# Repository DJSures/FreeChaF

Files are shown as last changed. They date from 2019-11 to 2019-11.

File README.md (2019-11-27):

# FreeChaF
This fork is of FreeChaF with changes to use the Fairchild Channel F original controllers and console buttons connected to a raspberry pi via Arduino Micro or Leonardo. Original Repo here: https://github.com/libretro/FreeChaF

In this repo, you will find David's modified FreeChaF for real hardware, and the arduino code that emulates USB joystick and USB keyboard devices. The wiring of each controller direction to corresponding arduino i/o pin is located in the INO file.

View DJ's build live hack here: https://synthiam.com/Community/HackEvents/Hacking-decision-C64-or-Fairchild-Channel-F-18819

# Folders
/3D Printing - contains the design files for 3d printing the console button holder

/Fairchild_Pi_Joystick_Paddle_Multi - Arduino Micro firmware for the USB joystick emulator

/Fairchild_Pi_Keyboard_Switches - Arduino Micro firmware for the USB keyboard emulator that emulates the console buttons

/FreeChaF-master - The lib retro freechaf emulator src modified for real hardware

# Dj's Hacked Fairchild Example

Channel F with raspberry pi and two arduinos emulating the joysticks and console buttons
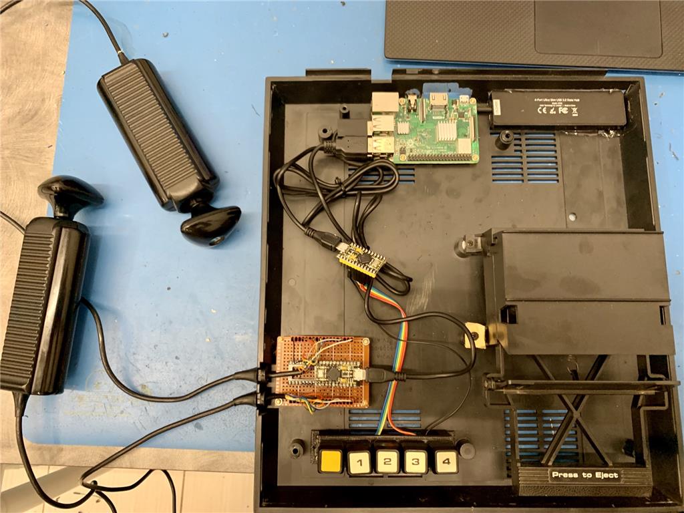
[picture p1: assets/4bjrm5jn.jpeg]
Image of hacked fairchild channel f


The raspberry pi mounted with stand-offs exposing the hdmi and power via a hole cut in the back of the channel f chassis
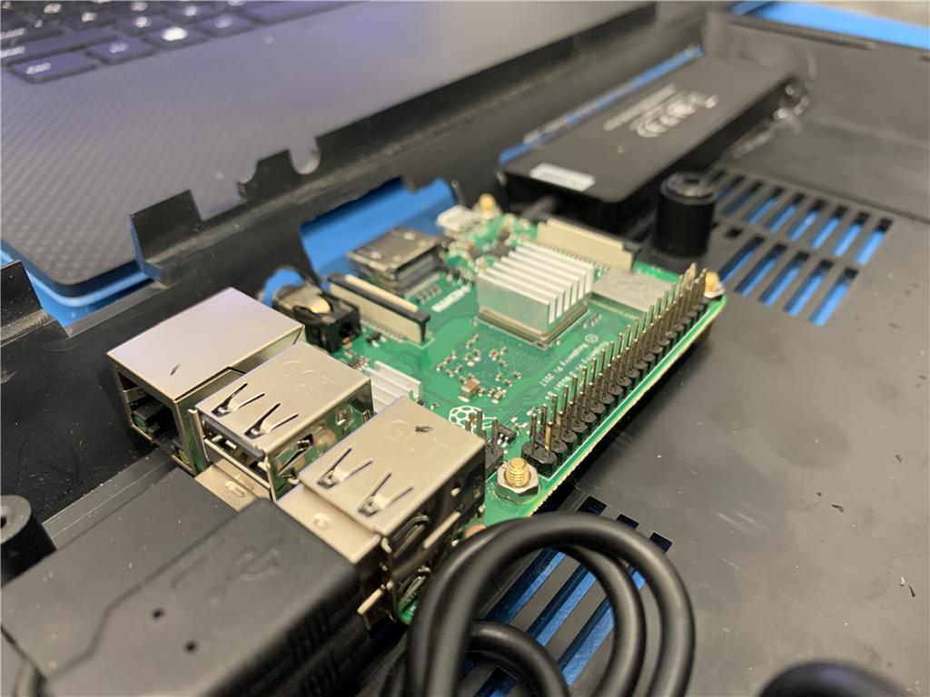
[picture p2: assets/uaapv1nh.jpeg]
Image of raspberry pi in fairchild channel f


The arduino micro that emulates a USB Keyboard device and connects to the console buttons
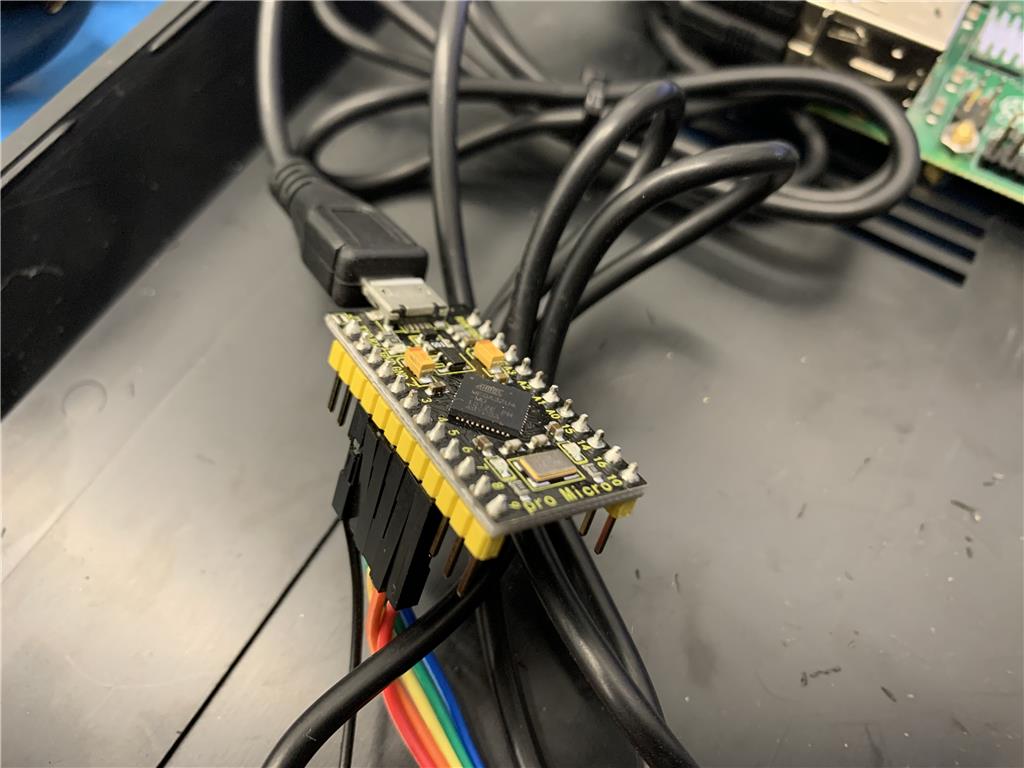
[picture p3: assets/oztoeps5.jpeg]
Image of Arduino for fairchild channel f console emulator


The console buttons held with a 3d printed bracket 
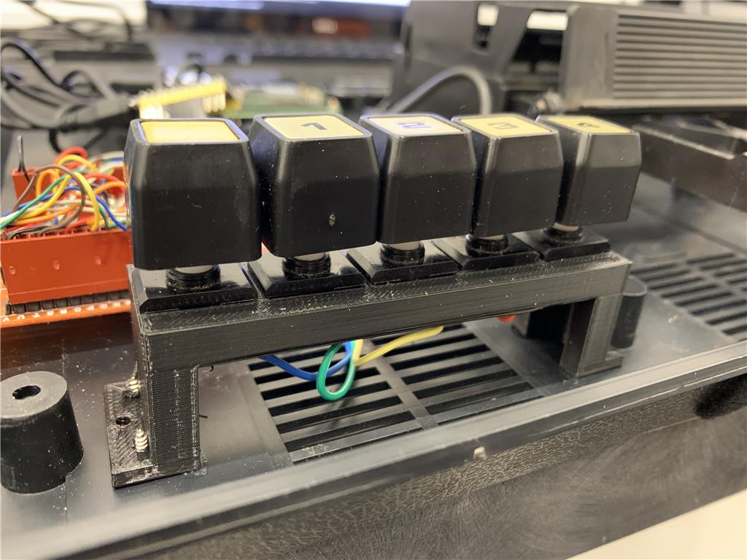
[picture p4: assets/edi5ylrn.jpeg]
Image of fairchild channel f console buttons 3d printed holder


The arduino micro that emulates 2 USB joysticks for the channel f joysticks
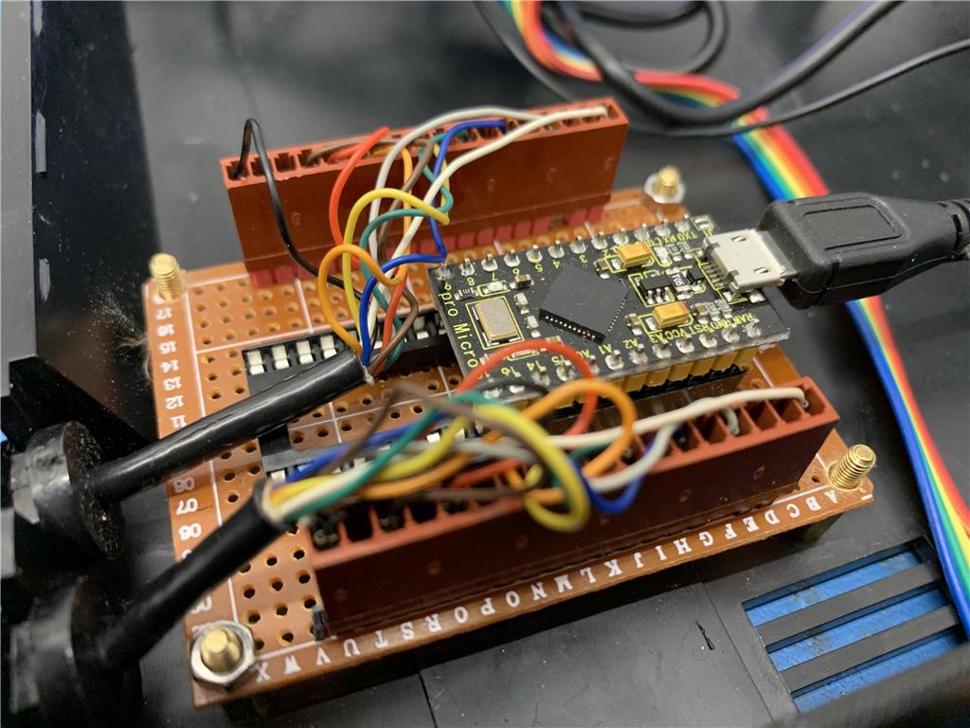
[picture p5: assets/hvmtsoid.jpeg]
Image of arduino joystick emulator for fairchild channel f


## Authors
FreeChaF was created by David Richardson.
This fork for real hardware by DJ Sures

## License
The FreeChaF core is licensed under GPLv3.

## BIOS
FreeChaF requires two BIOS files to be placed in the libretro 'system' folder:

| Filename | Description | MD5 |
|---|---|---|
| sl31253.bin | ChannelF BIOS (PSU 1) | ac9804d4c0e9d07e33472e3726ed15c3 |
| sl31254.bin | ChannelF BIOS (PSU 2) | da98f4bb3242ab80d76629021bb27585 |

If the ChannelF II BIOS is included, it will be used instead of sl31253.  All games are compatible with both.

| Filename | Description | MD5 |
|---|---|---|
| sl90025.bin | ChannelF II BIOS (PSU 1) | 95d339631d867c8f1d15a5f2ec26069d |

* BIOS filenames are case-sensitive

## Console buttons
Access to the console buttons are provided by the Arduino. The LibRetro configuration should have the assignments of numeric values 1, 2, 3, 4 to buttons A, B, X, Z. When a button is pressed, a console overlay will display that shows what button was pressed.

## Controls
| FreeChaF Function | Retropad | Keyboard Assignment |
| --- | --- | --- |
|Forward| Left-Analog Up||
|Backward| Left-Analog Down||
|Rotate Left | Right-Analog Left ||
|Rotate Right | Right-Analog Right ||
|Pull Up | Right-Analog Up ||
|Push Down | Right-Analog Down ||
|Show/Hide Console Overlay | Start | q |
|Controller Swap | Select | w |
|Reset | Left Trigger | R | 
|Console 1 | A | 1 |
|Console 2 | B | 2 |
|Console 3 | X | 3 | 
|Console 4 | Z | 4 |

## How to
Installing this in a fairchild channel f is quite easy. 

1) Open the fairchild channel f and remove the PCB

2) Disconnect the power adapter and joysticks

3) Desolder the console buttons (careful, this is an old machine)

4) 3D print the console button holder

5) Solder the console buttons with a common GND. Each other wire connects to the Arduino pins documented in the Arduino folder's Keyboard firmware code

6) Solder the joystick switches to the USB Joystick arduino micro. The pins are documented in the code. The WHITE wire gets GND

7) Program both of the Arduino's with their respective code

8) Build the freechaf for lib retro by copying the FreeChaf-Master folder to your raspberry pi

9) type make in the freechaf-master folder

10) chmod +x ./install.sh ; ./install.sh

11) load emulation station and configure the buttons appropiately 

12) Have fun!

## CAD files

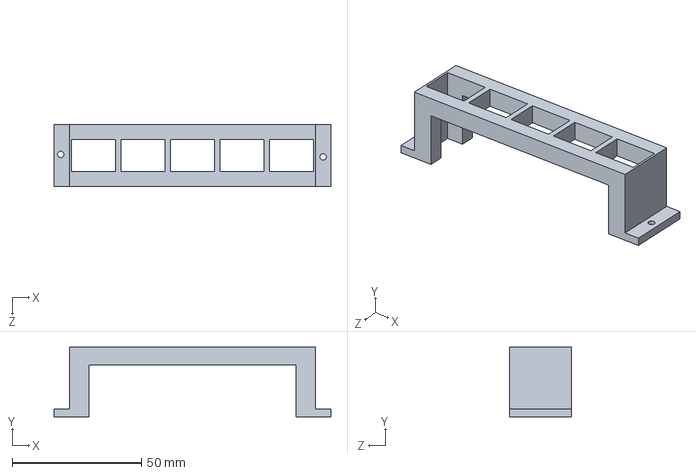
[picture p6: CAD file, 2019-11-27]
3D Printing/Button Holder.SLDPRT
107.0 x 27.0 x 24.0 mm

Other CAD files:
3D Printing/Button Holder.STL

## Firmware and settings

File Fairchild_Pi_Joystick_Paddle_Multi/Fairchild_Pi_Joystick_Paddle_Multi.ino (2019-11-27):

#include "Joystick.h"

// ***********************************************************************
// **                                                                   **
// ** Joystick USB HID for Teensy or Pro Micro                          **
// ** By DJ Sures (Synthiam.com) (c)2019                                **
// **                                                                   **
// ** Updated: November 16, 2019                                        **
// **                                                                   **
// ** NOTE                                                              **
// ** ~~~~                                                              **
// ** For this to work on Raspberry Pi (Linux), you need to add the     **
// ** the following to the /boot/cmdline.txt...                         **
// **                                                                   **
// ** usbhid.quirks=0x2341:0x8036:0x040    <- for Leonardo              **
// ** usbhid.quirks=0x2341:0x8037:0x040    <- for Micro                 **
// **                                                                   **
// ***********************************************************************

// uncomment to use for serial terminal debugging rather than usb hid device
// this is so you can see the ascii values to verify
//#define SERIAL_DEBUG

/**
  white - common
  grey - right
  blue - left
  green - reverse
  yellow - forward
  orange - twist left
  red - twist right
  brown - pull up
  black - push down
*/

#define J1RIGHT A3
#define J1LEFT A2
#define J1DOWN A1
#define J1UP A0

// button 0
#define J1TWIST_LEFT 15

// button 1
#define J1TWIST_RIGHT 14

// button 2
#define J1PUSH_DOWN 10

// button 3
#define J1PULL_UP 16

#define J2RIGHT 2
#define J2LEFT 3
#define J2DOWN 4
#define J2UP 5
#define J2TWIST_LEFT 6
#define J2TWIST_RIGHT 7
#define J2PUSH_DOWN 9
#define J2PULL_UP 8


Joystick_ _j1 = Joystick_(
                  0x03,
                  JOYSTICK_TYPE_JOYSTICK,
                  4,
                  0,
                  true,
                  true,
                  false,
                  false,
                  false,
                  false,
                  false,
                  false,
                  false,
                  false,
                  false
                );

Joystick_ _j2 = Joystick_(
                  0x06,
                  JOYSTICK_TYPE_JOYSTICK,
                  4,
                  0,
                  true,
                  true,
                  false,
                  false,
                  false,
                  false,
                  false,
                  false,
                  false,
                  false,
                  false
                );

byte _lastJ1X = 1; // 0 left, 1 center, 2 right
byte _lastJ1Y = 1; // 0 up, 1 center, 2 down
byte _lastJ1TWIST = 1; // 0 twist left, 1 center, 2 twist right
byte _lastJ1PUSH = 1; // 0 push down, 1 center, 2 pull up

byte _lastJ2X = 1; // 0 left, 1 center, 2 right
byte _lastJ2Y = 1; // 0 up, 1 center, 2 down
byte _lastJ2TWIST = 1; // 0 twist left, 1 center, 2 twist right
byte _lastJ2PUSH = 1; // 0 push down, 1 center, 2 pull up

void setup() {

#ifdef SERIAL_DEBUG
  Serial.begin(9600);
#else
  _j1.setXAxisRange(-127, 127);
  _j1.setYAxisRange(-127, 127);
  _j1.begin();

  _j2.setXAxisRange(-127, 127);
  _j2.setYAxisRange(-127, 127);
  _j2.begin();
#endif

  pinMode(J1UP, INPUT_PULLUP);
  pinMode(J1RIGHT, INPUT_PULLUP);
  pinMode(J1DOWN, INPUT_PULLUP);
  pinMode(J1LEFT, INPUT_PULLUP);
  pinMode(J1TWIST_LEFT, INPUT_PULLUP);
  pinMode(J1TWIST_RIGHT, INPUT_PULLUP);
  pinMode(J1PULL_UP, INPUT_PULLUP);
  pinMode(J1PUSH_DOWN, INPUT_PULLUP);

  pinMode(J2UP, INPUT_PULLUP);
  pinMode(J2RIGHT, INPUT_PULLUP);
  pinMode(J2DOWN, INPUT_PULLUP);
  pinMode(J2LEFT, INPUT_PULLUP);
  pinMode(J2TWIST_LEFT, INPUT_PULLUP);
  pinMode(J2TWIST_RIGHT, INPUT_PULLUP);
  pinMode(J2PULL_UP, INPUT_PULLUP);
  pinMode(J2PUSH_DOWN, INPUT_PULLUP);
}

void loop() {

#ifdef SERIAL_DEBUG

  Serial.print(digitalRead(J1UP));
  Serial.print(digitalRead(J1RIGHT));
  Serial.print(digitalRead(J1DOWN));
  Serial.print(digitalRead(J1LEFT));
  Serial.print(digitalRead(J1TWIST_LEFT));
  Serial.print(digitalRead(J1TWIST_RIGHT));
  Serial.print(digitalRead(J1PULL_UP));
  Serial.print(digitalRead(J1PUSH_DOWN));

  Serial.print(" ");

  Serial.print(digitalRead(J2UP));
  Serial.print(digitalRead(J2RIGHT));
  Serial.print(digitalRead(J2DOWN));
  Serial.print(digitalRead(J2LEFT));
  Serial.print(digitalRead(J2TWIST_LEFT));
  Serial.print(digitalRead(J2TWIST_RIGHT));
  Serial.print(digitalRead(J2PULL_UP));
  Serial.print(digitalRead(J2PUSH_DOWN));

  Serial.write("\r\n");

#else

  // ---------------------------------------------------------
  // JOYSTICK 1
  // ---------------------------------------------------------
  {
    byte j1y;

    if (!digitalRead(J1UP))
      j1y = 0;
    else if (!digitalRead(J1DOWN))
      j1y = 2;
    else
      j1y = 1;

    if (j1y != _lastJ1Y) {

      if (j1y == 0)
        _j1.setYAxis(-127);
      else if (j1y == 2)
        _j1.setYAxis(127);
      else
        _j1.setYAxis(0);

      _lastJ1Y = j1y;
    }
  }

  {
    // ---------------------------------------------------------
    byte j1x;

    if (!digitalRead(J1LEFT))
      j1x = 0;
    else if (!digitalRead(J1RIGHT))
      j1x = 2;
    else
      j1x = 1;

    if (j1x != _lastJ1X) {

      if (j1x == 0)
        _j1.setXAxis(-127);
      else if (j1x == 2)
        _j1.setXAxis(127);
      else
        _j1.setXAxis(0);

      _lastJ1X = j1x;
    }
  }

  {
    // ---------------------------------------------------------
    byte j1twist;

    if (!digitalRead(J1TWIST_LEFT))
      j1twist = 0;
    else if (!digitalRead(J1TWIST_RIGHT))
      j1twist = 2;
    else
      j1twist = 1;

    if (j1twist != _lastJ1TWIST) {

      if (j1twist == 0) {

        _j1.setButton(0, true);
        _j1.setButton(1, false);
      }  else if (j1twist == 2) {

        _j1.setButton(0, false);
        _j1.setButton(1, true);
      } else {

        _j1.setButton(0, false);
        _j1.setButton(1, false);
      }

      _lastJ1TWIST = j1twist;
    }
  }

  {
    // ---------------------------------------------------------
    byte j1push;

    if (!digitalRead(J1PUSH_DOWN))
      j1push = 0;
    else if (!digitalRead(J1PULL_UP))
      j1push = 2;
    else
      j1push = 1;

    if (j1push != _lastJ1PUSH) {

      if (j1push == 0) {

        _j1.setButton(2, true);
        _j1.setButton(3, false);
      }  else if (j1push == 2) {

        _j1.setButton(2, false);
        _j1.setButton(3, true);
      } else {

        _j1.setButton(2, false);
        _j1.setButton(3, false);
      }

      _lastJ1PUSH = j1push;
    }
  }

  // ---------------------------------------------------------
  // JOYSTICK 2
  // ---------------------------------------------------------
  {
    byte j2y;

    if (!digitalRead(J2UP))
      j2y = 0;
    else if (!digitalRead(J2DOWN))
      j2y = 2;
    else
      j2y = 1;

    if (j2y != _lastJ2Y) {

      if (j2y == 0)
        _j2.setYAxis(-127);
      else if (j2y == 2)
        _j2.setYAxis(127);
      else
        _j2.setYAxis(0);

      _lastJ2Y = j2y;
    }
  }

  {
    byte j2x;

    if (!digitalRead(J2LEFT))
      j2x = 0;
    else if (!digitalRead(J2RIGHT))
      j2x = 2;
    else
      j2x = 1;

    if (j2x != _lastJ2X) {

      if (j2x == 0)
        _j2.setXAxis(-127);
      else if (j2x == 2)
        _j2.setXAxis(127);
      else
        _j2.setXAxis(0);

      _lastJ2X = j2x;
    }
  }
  
  // ---------------------------------------------------------
  {
    byte j2twist;

    if (!digitalRead(J2TWIST_LEFT))
      j2twist = 0;
    else if (!digitalRead(J2TWIST_RIGHT))
      j2twist = 2;
    else
      j2twist = 1;

    if (j2twist != _lastJ2TWIST) {

      if (j2twist == 0) {

        _j2.setButton(0, true);
        _j2.setButton(1, false);
      }  else if (j2twist == 2) {

        _j2.setButton(0, false);
        _j2.setButton(1, true);
      } else {

        _j2.setButton(0, false);
        _j2.setButton(1, false);
      }

      _lastJ2TWIST = j2twist;
    }
  }

  {
    // ---------------------------------------------------------
    byte j2push;

    if (!digitalRead(J2PUSH_DOWN))
      j2push = 0;
    else if (!digitalRead(J2PULL_UP))
      j2push = 2;
    else
      j2push = 1;

    if (j2push != _lastJ2PUSH) {

      if (j2push == 0) {

        _j2.setButton(2, true);
        _j2.setButton(3, false);
      }  else if (j2push == 2) {

        _j2.setButton(2, false);
        _j2.setButton(3, true);
      } else {

        _j2.setButton(2, false);
        _j2.setButton(3, false);
      }

      _lastJ2PUSH = j2push;
    }
  }
  
#endif

  delay(25);
}

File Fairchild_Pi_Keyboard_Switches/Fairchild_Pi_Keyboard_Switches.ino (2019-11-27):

#include "Keyboard.h"

// ***********************************************************************
// **                                                                   **
// ** Keyboard USB HID for Teensy or Pro Micro                          **
// ** By DJ Sures (Synthiam.com) (c)2019                                **
// **                                                                   **
// ** Updated: November 15, 2019                                        **
// **                                                                   **
// ***********************************************************************

// uncomment to use for serial terminal debugging rather than usb hid device
// this is so you can see the ascii values to verify
//#define SERIAL_DEBUG

#define SWITCH_RESET 2
#define SWITCH_S1 3
#define SWITCH_S2 4
#define SWITCH_S3 5
#define SWITCH_S4 6

bool _last_reset = false;
bool _last_s1 = false;
bool _last_s2 = false;
bool _last_s3 = false;
bool _last_s4 = false;
bool _last_start = false;
bool _last_select = false;

void setup() {

#ifdef SERIAL_DEBUG
  Serial.begin(9600);
#else
  Keyboard.begin();
#endif

  pinMode(SWITCH_RESET, INPUT_PULLUP);
  pinMode(SWITCH_S1, INPUT_PULLUP);
  pinMode(SWITCH_S2, INPUT_PULLUP);
  pinMode(SWITCH_S3, INPUT_PULLUP);
  pinMode(SWITCH_S4, INPUT_PULLUP);
}

void loop() {

#ifdef SERIAL_DEBUG

  Serial.print(!digitalRead(SWITCH_RESET));
  Serial.print(!digitalRead(SWITCH_S1));
  Serial.print(!digitalRead(SWITCH_S2));
  Serial.print(!digitalRead(SWITCH_S3));
  Serial.print(!digitalRead(SWITCH_S4));
  Serial.print("\r\n");

#else

  bool reset = !digitalRead(SWITCH_RESET);
  bool s1 = !digitalRead(SWITCH_S1);
  bool s2 = !digitalRead(SWITCH_S2);
  bool s3 = !digitalRead(SWITCH_S3);
  bool s4 = !digitalRead(SWITCH_S4);
  bool select = !digitalRead(SWITCH_RESET) && !digitalRead(SWITCH_S1);
  bool start = !digitalRead(SWITCH_RESET) && !digitalRead(SWITCH_S2);

 if (select != _last_select) {

    if (select) 
      Keyboard.press('q');
    else
      Keyboard.release('q');

    _last_select = select;
  }

  if (start != _last_start) {

    if (start) 
      Keyboard.press('w');
    else
      Keyboard.release('w');

    _last_start = start;
  }

  // no need to process anything further because 
  if (reset || select || start)
    return;

  if (reset != _last_reset) {

    if (reset) {

        // TODO: emulator needs support for RESET button
        // exit emulator now by pressing SELECT & START (reset + time + mode)
//      Keyboard.press('q');
//      Keyboard.press('w');
//      delay(250);
//      Keyboard.releaseAll();
    }

    _last_reset = reset;
  }
  
  if (s1 != _last_s1) {

    if (s1)
      Keyboard.press('1');
    else
      Keyboard.release('1');

    _last_s1 = s1;
  }

  if (s2 != _last_s2) {

    if (s2)
      Keyboard.press('2');
    else
      Keyboard.release('2');

    _last_s2 = s2;
  }

  if (s3 != _last_s3) {

    if (s3)
      Keyboard.press('3');
    else
      Keyboard.release('3');

    _last_s3 = s3;
  }

  if (s4 != _last_s4) {

    if (s4)
      Keyboard.press('4');
    else
      Keyboard.release('4');

    _last_s4 = s4;
  }

#endif

  delay(50);
}

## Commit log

2019-11-27 Arduino firmware for USB keyboard and USB Joystick
2019-11-27 FreeChaf SRC with edits for real hardware
    Comments are added for all changes from David's original repo
    [emulators.cfg, retroarch.cfg]
2019-11-27 removed duplicates
    [emulators.cfg, retroarch.cfg]
2019-11-27 3d printing
    added design files for the 3d printing console holder
    [Button Holder.SLDPRT, Button Holder.STL]
